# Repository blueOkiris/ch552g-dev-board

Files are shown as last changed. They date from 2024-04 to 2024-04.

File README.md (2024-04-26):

# CH552G Dev Board

## Description

A simple breakout board with minimal hardware design for the CH552g as well as a C project to be used as a basis.

I've become fond of the CH552g for projects as it's simple like AVR unlike something like ARM, but it doesn't require a programmer and has built-in USB support from the factory, unlike something like AVR but like ARM.

To ensure I don't have to constantly order pcb after pcb, I've created this dev board that can go on a breadboard, so I can prototype with the chip more easily.

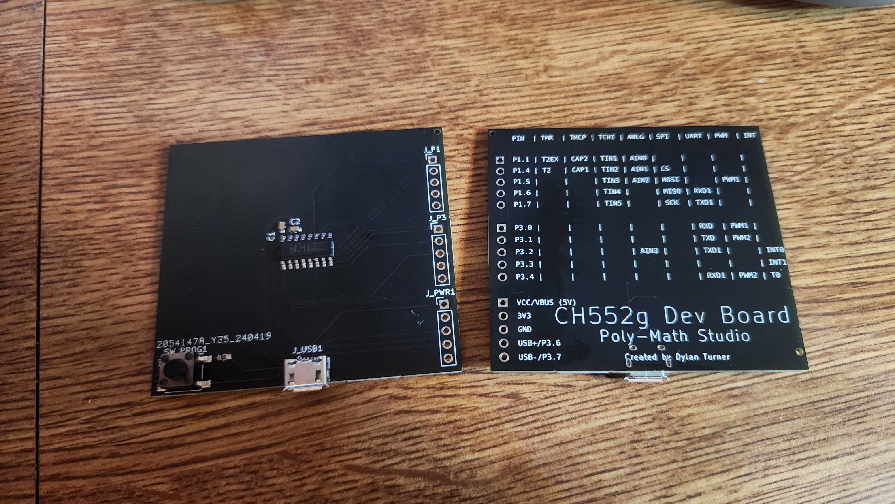
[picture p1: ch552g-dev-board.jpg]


## Order Boards

Open up KiCAD and export the Gerber and Drill files and zip them up or grab a zip from Releases.

Then go to JLCPCB's website, start a new order with the zip file, and select PCB Assembly.

Then upload the provided BOM and CPL (in the pcb/ folder) and submit an order.

## Build Example Code 

First, clone the repo, then make sure you clone all submodules: `git submodule update --init --recursive`

### Dependencies

- Linux:
   + Just use [nix](https://nixos.org/download/). Use `nix-shell` to get the following:
      - gnumake
      - hidapi
      - libusb1
      - libusb
      - python3
      - sdcc
      - virtualenv which will create .venv w/
         + pyusb
         + ch55xtool
- Windows:
   + Install [sdcc](https://sourceforge.net/projects/sdcc/files/latest/download?source=files)
   + Install [mingw](https://sourceforge.net/projects/mingw/files/latest/download)
   + Install [WCHISPTool](https://www.wch.cn/download/WCHISPTool_Setup_exe.html)
      - Only relevant for uploading, not building

### Build

On Linux, make sure you have the python virtualenv active and sdcc in your path (this happens every time you run `nix-shell`)

Run `make -C example-code` (or `mingw32-make -C example-code`), and it will build everything.

### Upload

__Linux:__

Assuming the program has been built, to upload:

1. Hold down a button on the board you want to upload to
2. Plug into USB and let go of the button
3. Within 2 seconds of letting go, run `make -C example-code upload`

If it fails, just try again a few times. If it's still not working, then repeat the process.

__Windows:__

Use WCHISP Studio

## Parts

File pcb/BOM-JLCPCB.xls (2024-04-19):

Comment | Designator | Footprint | JLCPCB Part#(optional)
Tactile Push Switch | SW_PROG1 | SMD, 6mmx6mm | C455110
CH552G | IC1 | SOP-16 | C111292
10k Ohm Resistor | R_PROG1 | 0603 | C234237
100nF Capacitor | C1,C2 | 0603 | C913909
USB Micro-B | J_USB1 | Through Hole | C132563

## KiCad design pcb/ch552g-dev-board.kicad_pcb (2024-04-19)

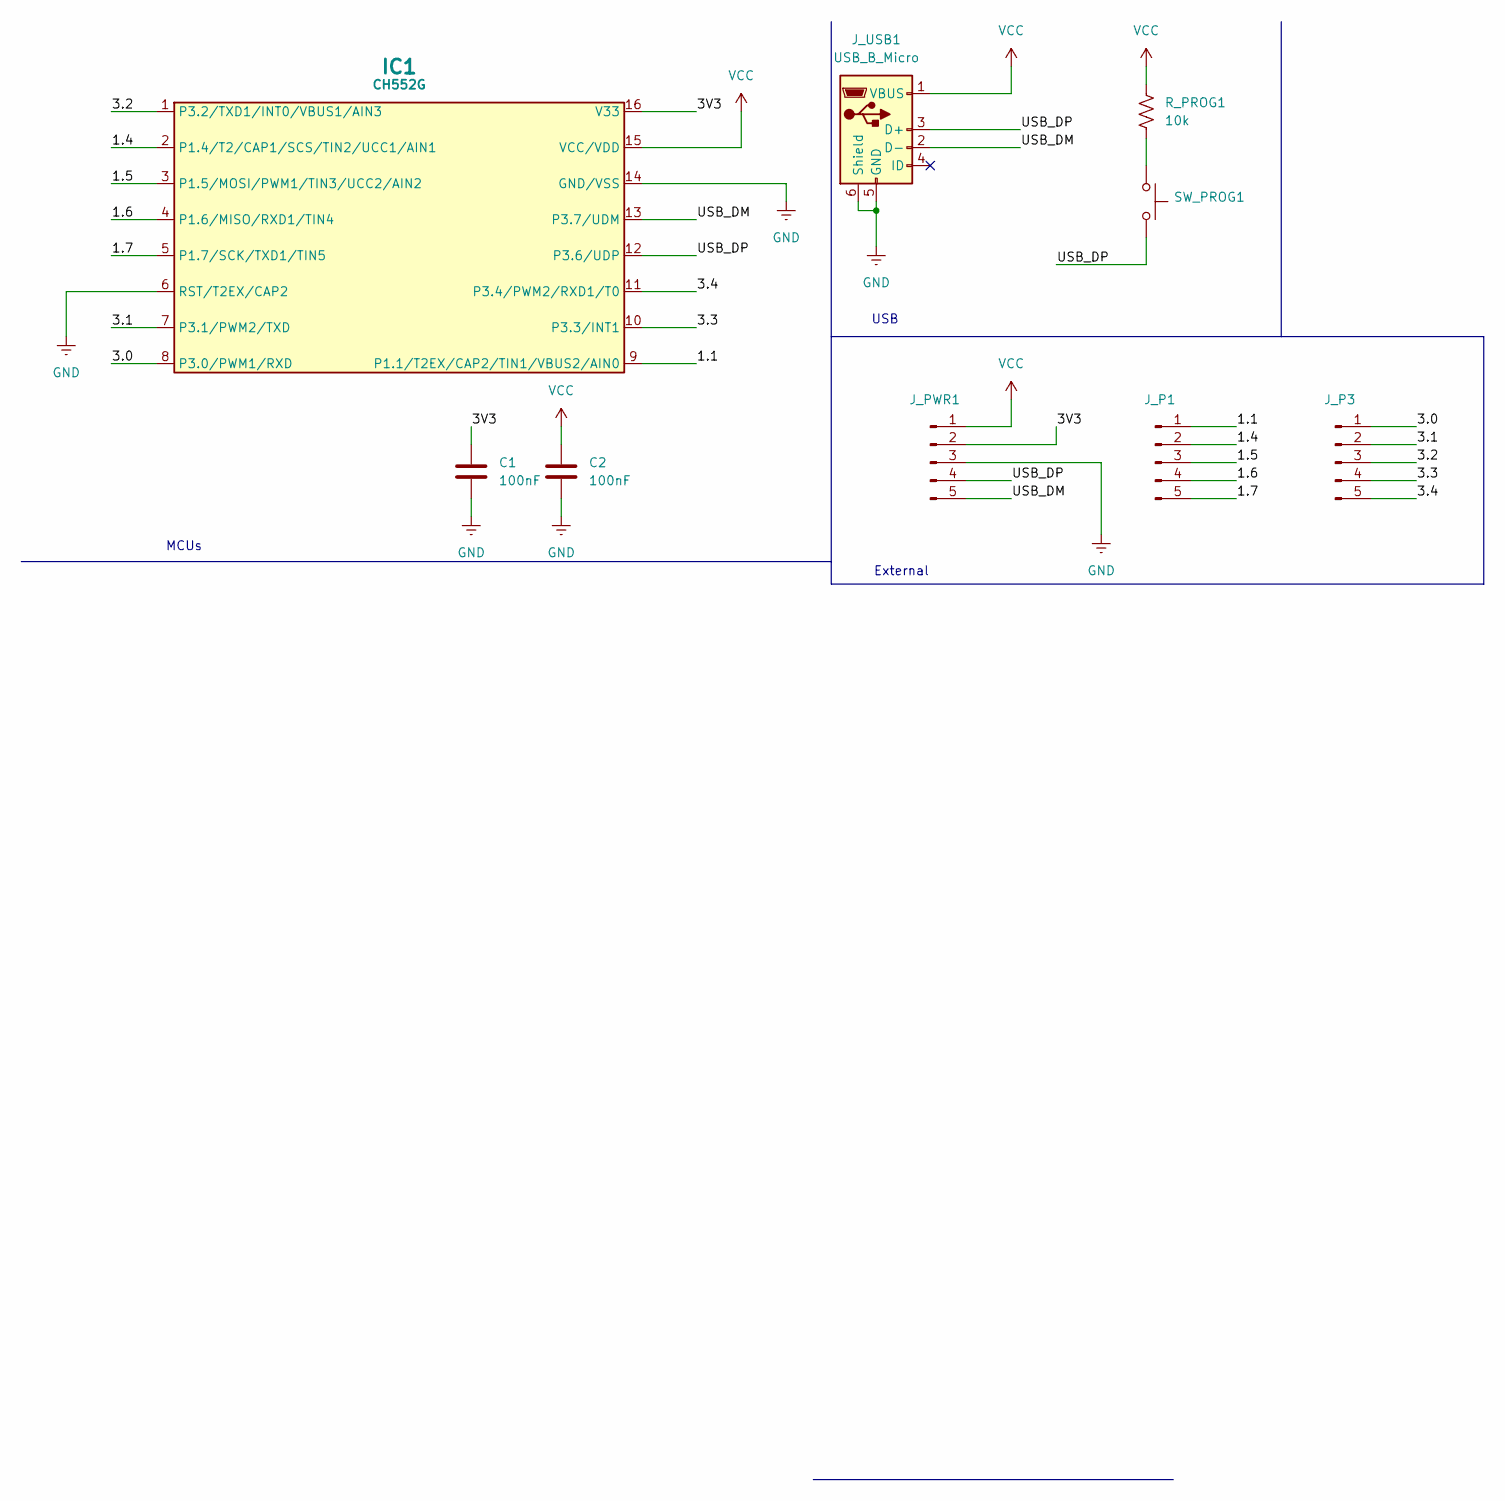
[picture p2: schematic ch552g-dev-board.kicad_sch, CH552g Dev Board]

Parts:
C1, C2: 100nF; C_0603_1608Metric
IC1: CH552G; SOIC-16_3.9x9.9mm_Pitch1.27mm
J_P1, J_P3: PinHeader_1x05_P2.54mm_Vertical
J_PWR1: PinHeader_1x05_P2.54mm_Vertical
J_USB1: USB_B_Micro; USB_Micro-B_Amphenol_10118194_Horizontal
R_PROG1: 10k; R_0603_1608Metric
SW_PROG1: SW_Push_1P1T_NO_6x6mm_H9.5mm

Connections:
/1.1: IC1.9 (P1.1/T2EX/CAP2/TIN1/VBUS2/AIN0), J_P1.1
/1.4: IC1.2 (P1.4/T2/CAP1/SCS/TIN2/UCC1/AIN1), J_P1.2
/1.5: IC1.3 (P1.5/MOSI/PWM1/TIN3/UCC2/AIN2), J_P1.3
/1.6: IC1.4 (P1.6/MISO/RXD1/TIN4), J_P1.4
/1.7: IC1.5 (P1.7/SCK/TXD1/TIN5), J_P1.5
/3.0: IC1.8 (P3.0/PWM1/RXD), J_P3.1
/3.1: IC1.7 (P3.1/PWM2/TXD), J_P3.2
/3.2: IC1.1 (P3.2/TXD1/INT0/VBUS1/AIN3), J_P3.3
/3.3: IC1.10 (P3.3/INT1), J_P3.4
/3.4: IC1.11 (P3.4/PWM2/RXD1/T0), J_P3.5
/3V3: C1.1, IC1.16 (V33), J_PWR1.2
/USB_DM: IC1.13 (P3.7/UDM), J_PWR1.5, J_USB1.2 (D-)
/USB_DP: IC1.12 (P3.6/UDP), J_PWR1.4, J_USB1.3 (D+), SW_PROG1.2
GND: C1.2, C2.2, IC1.6 (RST/T2EX/CAP2), IC1.14 (GND/VSS), J_PWR1.3, J_USB1.5 (GND), J_USB1.6 (Shield)
unnamed: R_PROG1.2, SW_PROG1.1
VCC: C2.1, IC1.15 (VCC/VDD), J_PWR1.1, J_USB1.1 (VBUS), R_PROG1.1

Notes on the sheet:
External
USB
MCUs

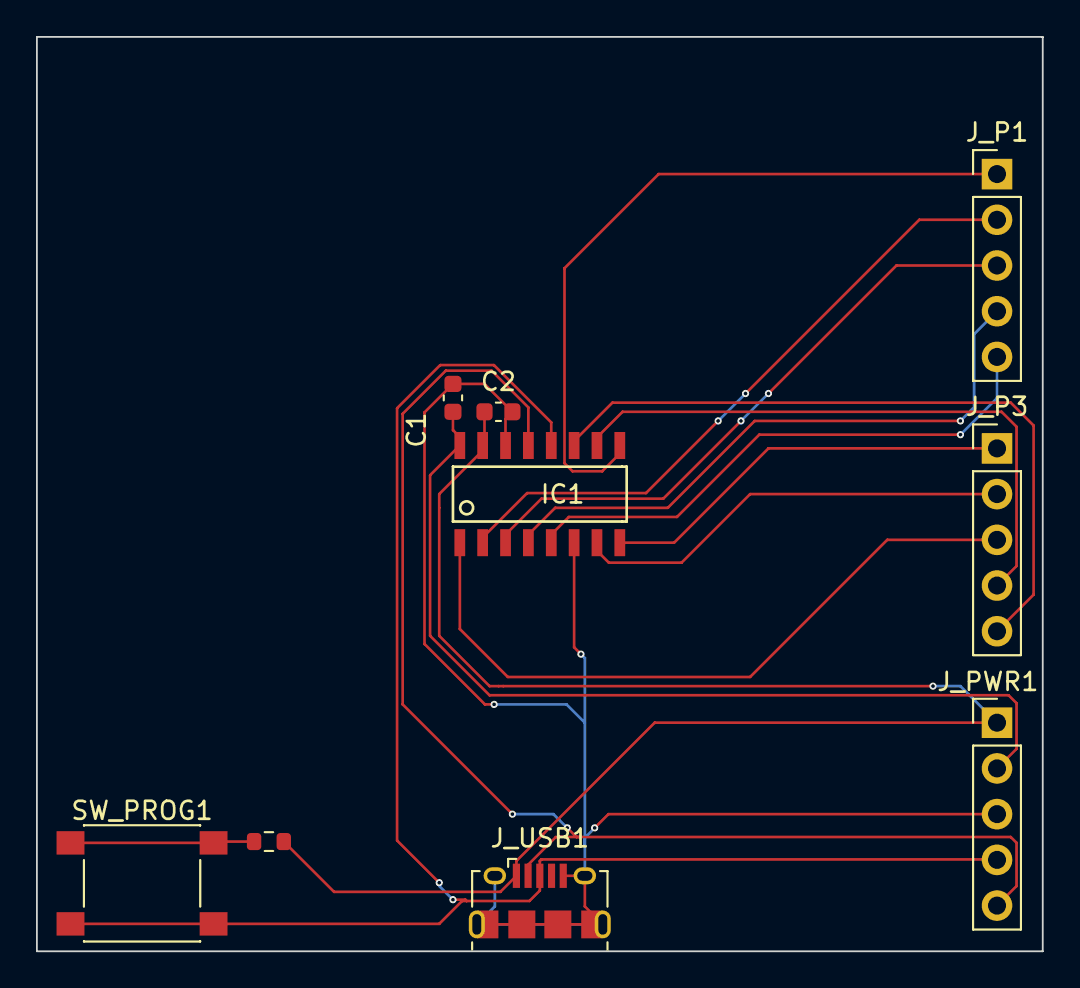
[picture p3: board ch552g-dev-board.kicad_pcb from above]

Board: 2 copper layers, 55.9 x 50.8 mm, 9 parts (0 on the bottom side), 16 nets.

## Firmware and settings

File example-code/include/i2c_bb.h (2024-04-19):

// API for complete bit-banged I2C library (since ch554_sdcc one doesn't really work)

#pragma once

#include <stdint.h>

// Change SDA_PORT/PIN and SCL_PORT/PIN to set your desired I2C ports
#define SDA_PORT_PU     P1_DIR_PU
#define SDA_PORT_OC     P1_MOD_OC
#define SDA_PORT        P1
#define SDA_PIN         6
#define SCL_PORT_PU     P1_DIR_PU
#define SCL_PORT_OC     P1_MOD_OC
#define SCL_PORT        P1
#define SCL_PIN         7

/*
 * Usage:
 *
 * At start of program:
 *     i2c_bb_init();
 *
 * To write data:
 *     i2c_bb_start(SLAVE_ADDRESS);
 *     i2c_bb_write(<data 1>);
 *     i2c_bb_write(<data 2>);
 *     ...
 *     i2c_bb_stop();
 * or something like:
 *     i2c_bb_start(SLAVE_ADDRESS);
 *     for (size_t i = 0; i < DATA_LEN; i++) {
 *         i2c_bb_write(data[i]);
 *     }
 *     i2c_bb_stop();
 *
 * To read data:
 *     i2c_bb_start(SLAVE_ADDRESS);
 *     uint8_t data = i2c_read();
 *     i2c_bb_stop();
 */

void i2c_bb_init(void);
void i2c_bb_start(const uint8_t addr);
void i2c_bb_write(const uint8_t data);
uint8_t i2c_bb_read(void);
void i2c_bb_stop(void);

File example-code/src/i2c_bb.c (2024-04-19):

// Implement bit-banging for I2C

#include <stdint.h>
#include <8051.h>
#include <ch554.h>
#include <debug.h>
#include <i2c_bb.h>

uint8_t SDA_PIN_BIT = 0;
uint8_t SCL_PIN_BIT = 0;

void set_sda(uint8_t on) {
    if (on) {
        SDA_PORT |= SDA_PIN_BIT;
    } else {
        SDA_PORT &= ~SDA_PIN_BIT;
    }
}

uint8_t get_sda(void) {
    return SDA_PORT & SDA_PIN_BIT > 0;
}

void read_ack(void) {
    SDA_PORT |= SDA_PIN_BIT;
    SCL_PORT |= SCL_PIN_BIT;

    // Set SDA to input to "read"
    SDA_PORT_PU &= ~SDA_PIN_BIT;
    SCL_PORT &= ~SCL_PIN_BIT;

    SDA_PORT_PU |= SDA_PIN_BIT;
}

void i2c_bb_init(void) {
    SDA_PIN_BIT = 1 << SDA_PIN;
    SCL_PIN_BIT = (uint8_t) (1 << SCL_PIN);

    // Put SDA and SCL into output mode
    SDA_PORT_PU |= SDA_PIN;
    SDA_PORT_OC &= ~SDA_PIN;
    SCL_PORT_PU |= SCL_PIN;
    SCL_PORT_OC &= ~SDA_PIN;

    SDA_PORT |= SDA_PIN_BIT;
    SCL_PORT |= SCL_PIN_BIT;
}

void i2c_bb_start(const uint8_t addr) {
    // Begin transmission
    SDA_PORT &= ~SDA_PIN_BIT;
    SCL_PORT &= ~SCL_PIN_BIT;

    // Set addr & R/W
    const uint8_t data = (addr << 1) + 0; // Do "+ 1" for Read
    for (int8_t i = 7; i >= 0; i--) {
        set_sda((data >> i) & 0x01);
        SCL_PORT |= SCL_PIN_BIT;
        SCL_PORT &= ~SCL_PIN_BIT;
    }
    read_ack();
}

void i2c_bb_write(const uint8_t data) {
    for (int8_t i = 7; i >= 0; i--) {
        set_sda((data >> i) & 0x01);
        SCL_PORT |= SCL_PIN_BIT;
        SCL_PORT &= ~SCL_PIN_BIT;
    }
    read_ack();
}

uint8_t i2c_bb_read(void) {
    uint8_t data;

    SDA_PORT_PU &= ~SDA_PIN_BIT; // Set SDA to input to "read"
    for (int8_t i = 7; i >= 0; i--) {
        SCL_PORT |= SCL_PIN_BIT;
        data |= get_sda() << i;
        SCL_PORT &= ~SCL_PIN_BIT;
    }
    read_ack(); // Sets back to write for us

    return data;
}

void i2c_bb_stop(void) {
    SDA_PORT |= SDA_PIN_BIT;
    SCL_PORT |= SCL_PIN_BIT;
}

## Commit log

2024-04-19 Rev 1
    [BOM-JLCPCB.xls, ch552g-dev-board.kicad_pcb, ch552g-dev-board.kicad_sch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]
2024-04-25 Removed lock board
2024-04-26 README: add dev board
2024-04-26 ch552g-dev-board.jpg: added
